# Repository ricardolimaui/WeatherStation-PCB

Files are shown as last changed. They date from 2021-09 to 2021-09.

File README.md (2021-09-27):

# Unparallel Weather Station PCB

The Unparallel Weather Station allows anyone to build their own low-cost weather station, using our custom open-source PCB. The software for the weather station is also open-source and can be used as is, or freely customized to meet your own needs and requirements. A model for printing a 3D case for your weather station is also provided.

This Weather Station PCB is a board to simplify the assembly of a weather station using low-cost hardware and a LoPy4 board. The LoPy4 board is equipped with several connectivity options (e.g. Sigfox, LoRa, Wi-Fi and Bluetooth). Currently, the weather station uses Sigfox and/or Wi-Fi to send the data to the cloud, however, the software can be extended to support other connectivity options. A Grafana dashboard is then used to display the historical weather data that is stored on the cloud.

The weather station uses an external sensor (AM2315) for reading temperature and relative humidity, a weather meter kit (SEN-15901) for wind speed, wind direction and precipitation. The weather station is powered from a Li-Ion battery that is charged with a photovoltaic panel which is also used to measure solar radiation. Due to the system’s low-power operation and solar energy harvesting features, it is energy autonomous and can be deployed in remote places.

## Measured parameters:  
*	Temperature (ºC)
*	Relative Humidity (%)
*	Rain (mm/h)
*	Wind Speed (km/h)
*	Wind Gust Speed (km/h)
*	Wind Direction (degrees)
*	Wind Gust Direction (degrees)
*	Solar Radiation (W/m2)
*	Battery Voltage (V)

## Parts list:  
*	Unparallel Weather Station PCB
*	Unparallel Weather Station 3D printed case (optional)
*	AM2315 - Encased I2C Temperature/Humidity Sensor
*	Weather Meter Kit - SEN-15901
*	Li-Ion battery (recommended 3.65V; 8Ah)
*	2.5W Solar Panel (116x160mm)
*	Sigfox antenna (868MHz)
*	LoPy 4.0

This work was done in the context of SmartAgriHubs Research Project, which has received funding from the European Union’s Horizon 2020 research and innovation programme under grant agreement No 818182

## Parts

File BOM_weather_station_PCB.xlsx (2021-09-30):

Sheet: pcb weatherstation
Qty per brd | Value | Device | Schematic Reference | Manufacturer Part Number (MPN) | MFR | Description
1 | - | LEDCHIP-LED0805 | LED1 | LG R971-KN-1 | Osram Opto Semiconductor | Standard LEDs - SMD 0805 Green, 570nm 26mcd, 20mA
1 | - | MCP73831/2 | U2 | MCP73831T-2ACI/OT | Microchip | Battery Management Charge
1 | - | PINHD-1X2 | JP2 | DS1023-1*2S21 | CONNFLY | Female; PIN: 2; straight; 2.54mm; THT; 1x2; 3A
1 | - | PINHD-1X6 | NCDW-06 | DS1023-1*6S21 | CONNFLY | Female; PIN: 6; straight; 2.54mm; THT; 1x6; 3A
2 | - | W237-102 | DC_IN SOLAR_POWER | DG300-5.0-2P12 | DEGSON ELECTRONICS | PCB terminal block; angled 90°; 5mm; ways: 2; on PCBs; 2.5mm2; 24A
2 | - | W237-4 | SENSOR1 | DG300-5.0-2P12 | DEGSON ELECTRONICS | PCB terminal block; angled 90°; 5mm; ways: 2; on PCBs; 2.5mm2; 24A
3 | 100k | R-EU_R0603 | R19 R20 R30 | RC0603FR-07100KL | YAGEO | Thick Film Resistors - SMD 0603 100 kOhms 100mW 0603 1%
2 | 100n | C-EUC0603 | C4 C9 | CC0603KRX7R8BB104 | YAGEO | MLCC - SMD/SMT 0603 25V 0.1uF X7R 0603 10%
2 | 10R | R-EU_R0603 | R11 R12 | CRCW060310R0FKEAC | Vishay | Thick Film Resistors - SMD 0603 1/10Watt 10ohms 1% Commercial Use
3 | 10k | R-EU_R0603 | R14 R15 R26 | CR0603-FX-1002ELF | Bourns | Thick Film Resistors - SMD 0603 10K 1% 1/10W
2 | 10n | C-EUC0603/C0805_PROTO | C1 C2 | 885012206089 | Wurth Elektronik | MLCC - SMD/SMT WCAP-CSGP 0.01uF 0603 10% 50V
7 | 1k | R-EU_R0603 | R1 R2 R3 R5 R6 R7 R18 | CR0603-FX-1001ELF | Bourns | Thick Film Resistors - SMD 0603 1K 1% 1/10W
1 | 2k74 | R-EU_R0603/R0805_PROTO | R29 | RC0603FR-132K74L | YAGEO | Thick Film Resistors - SMD 0603 2.74kOhms 1/10W 0603 1%
3 | 1u | C-EUC0603/C0805_PROTO | C5 C6 C7 | C0805C105K3RACTU | KEMET | MLCC - SMD/SMT 25V 1uF X7R 0805 10%
2 | 200k | R-EU_R0603/R0805_PROTO | R23 R25 | CRCW0603200KFKEAC | Vishay | Thick Film Resistors - SMD 0603 1/10Watt 200Kohms 1%
1 | 200m | R-EU_R0603/R0805_PROTO | R10 | RL1220S-R20-F | Susumu | Current Sense Resistors - SMD 0805 1/3W 0.20ohm 1%
1 | 220n | C-EUC0603 | C3 | CC0603KRX7R7BB224 | YAGEO | MLCC - SMD/SMT 16V 0.22uF X7R 0603 10%
4 | 47k | R-EU_R0603 | R13 R22 R27 R33 | RC0603FR-0747KL | YAGEO | Thick Film Resistors - SMD 47 kOhms 100mW 0603 1%
2 | 499k | R-EU_R0603/R0805_PROTO | R9 R24 | CR0603-FX-4993ELF | Bourns | Thick Film Resistors - SMD 499K ohm 1%
1 | 4k7 | R-EU_R0603/R0805_PROTO | R4 | RC0603FR-074K7L | YAGEO | Thick Film Resistors - SMD 4.7 kOhms 100mW 0603 1%
1 | 4u7 | C-EUC0603/C0805_PROTO | C8 | GRM21BZ7YA475KE15L | Murata | MLCC - SMD/SMT 35V 4.7uF X7R 0805 10%
3 | BSS138 | BSS138 | Q2 Q5 Q6 | BSS138-7-F | Diodes Incorporated | MOSFET 300mW 50V DSS SOT-23-3 N-channel
1 | CC/10k | R-EU_R0603 | R16 | Soldering Shunt
1 | CZRB5339B-HF | ZENER-DIODE-PROTO | D11 or D9 | CZRB5339B-HF Or 1N5339B-TP | Comchip Technology Or Micro Commercial Components (MCC) | Zener Diodes ZENER 5W 5.6V SMB DO-214AA-2 Or Zener Diodes 5.0W 5.6V 1uA 865mA 13.4A DO-15-2
1 | INA219BIDCNT | INA219BIDCNT | U1 | INA219BIDCNR | Texas Instruments | Current & Power Monitors & Regulators 0-Drift,Bi-dir Current/Pwr Monitor
2 | LOPY4 pinheader | LOPY4_SHIELD | U$2 | DS1023-1*14S21 | CONNFLY | Female; PIN: 14; straight; 2.54mm; THT; 1x14; 3A | e.g. https://www.adafruit.com/product/2940
1 | 220k | R-EU_R0603/R0805_PROTO | R8 | RC0603FR-0722KL | YAGEO | Thick Film Resistors - SMD 22 kOhms 100mW 0603 1%
2 | 0ZCK0075FF2E | PTC-0805 | F1 F2 | 0ZCK0075FF2E | Bel | Resettable Fuses - PPTC Hold current 750 mA 0805
2 | RFN2LAM4STFTR/SS14L | SCHOTTKY-DIODESMA_SOD-128_PROTO | D3 D10 | RFN2LAM4STFTR | ROHM Semiconductor | Diodes 400V VR 1.5A IO SOD-128; PMDTM
2 | RJ11 | RJ11-6 | J1_RAIN J2_WIND | 95501-2661 | Molex | Ethernet Connectors RA 6/6 RJ12 LOW PROFILE THT
1 | S2B-PH-SM4 | JST_2PIN-SMT-RA | CN1 | S2B-PH-SM4-TB | JST | Male; PH; 2mm; PIN: 2; SMT
2 | SI2333DDS_PROTO | SI2333DDS_PROTO | Q1 Q3 | SI2333DDS-T1-GE3 | Vishay | Transistor: P-MOSFET; unipolar; -12V; -5.2A; Idm: -20A; 1.1W; SOT23
1 | SN74AUP2G14DCKR | SN74AUP2G14-DCKR | U3 | SN74AUP2G14DCKR | Texas Instruments | Inverters Lo-Pwr Dual Schmitt- Trigger Inverter SC70-6
7 | SS12L | SCHOTTKY-DIODESUB_SMA_PROTO | D1 D2 D4 D6 D7 D8 D5 | SS14L | Taiwan Semiconductor | Schottky Rectifiers Sub SMA-2
1 | CC |  | JP1 | Soldering Shunt to vbat

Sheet: Part_list weatherstation
Qtd | Device | MPN | MFR | Description
1 | Battery (3.65V; 8Ah) | CL-18650-29E/1S3P | CELLEVIA BATTERIES | Li-Ion; Cell: SAMSUNG; 18650,MR18650; 3.65V; 8000mAh
1 | LoPy 4.0 | LoPy 4.0 | Pycom | WiFi Development Tools - 802.11 Sigfox, LoRa, 433MHZ BLE & WIFI Dev board
1 | Sigfox antenna (868MHz) | LoRa (868MHz/915MHz) & Sigfox Antenna Kit | Pycom | External antenna RF Cable Assemblies SMA(F)
1 | Solar Panel | 313070000 | Seeed Studio | Solar Panels 2.5W Solar Panel 116X160
1 | Temperature and Humidity sensor | AM 2315 (1293) | Adafruit | I2C Temp Humidity Sensor
1 | Weather Meters kit | SEN-15901 | SparkFun Electronics | Multiple Function Sensor Development Tools Weather Meter Kit (Rainfall, Weather, Wind Direction, Wind Speed)
1 | 3D box
1 | Weather Station PCB | Weather Station PCB

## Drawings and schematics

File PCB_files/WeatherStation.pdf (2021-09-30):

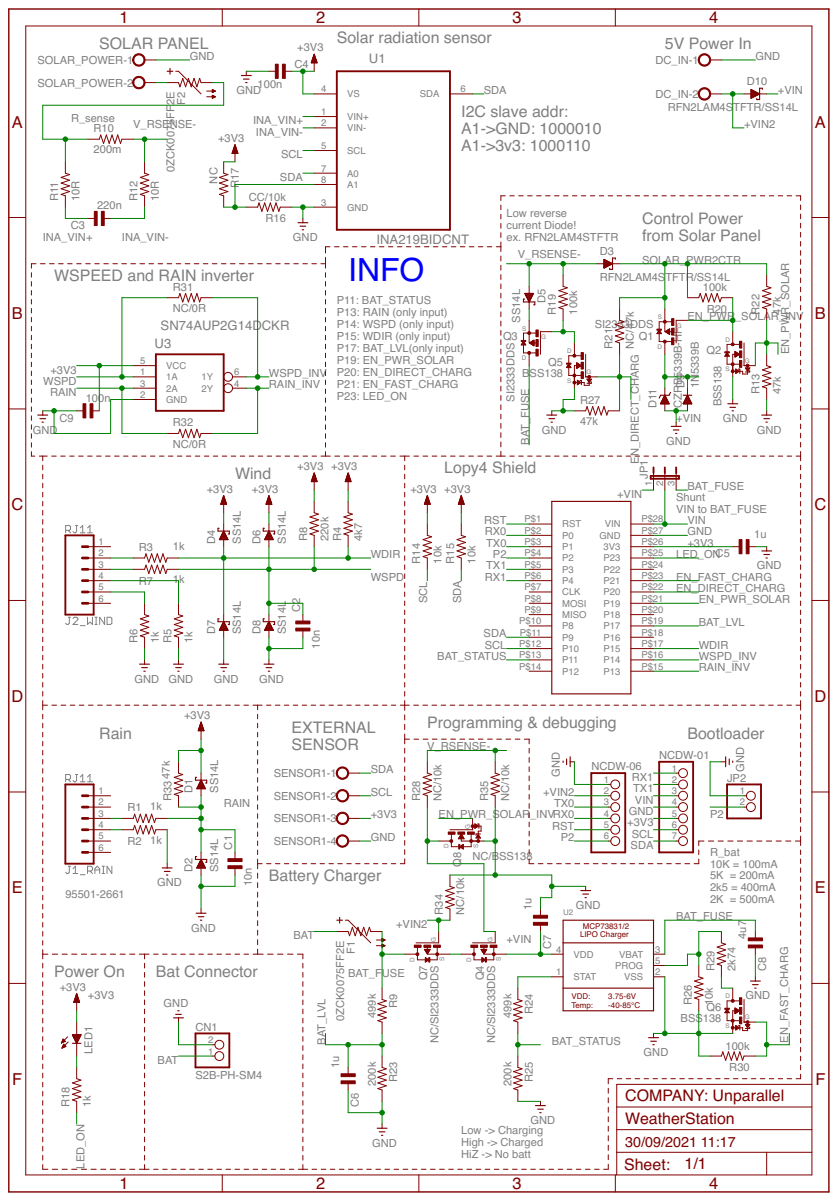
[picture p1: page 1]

Solar radiation sensor
NC/BSS138 NC/10k Low reverse

WSPEED and RAIN inverter

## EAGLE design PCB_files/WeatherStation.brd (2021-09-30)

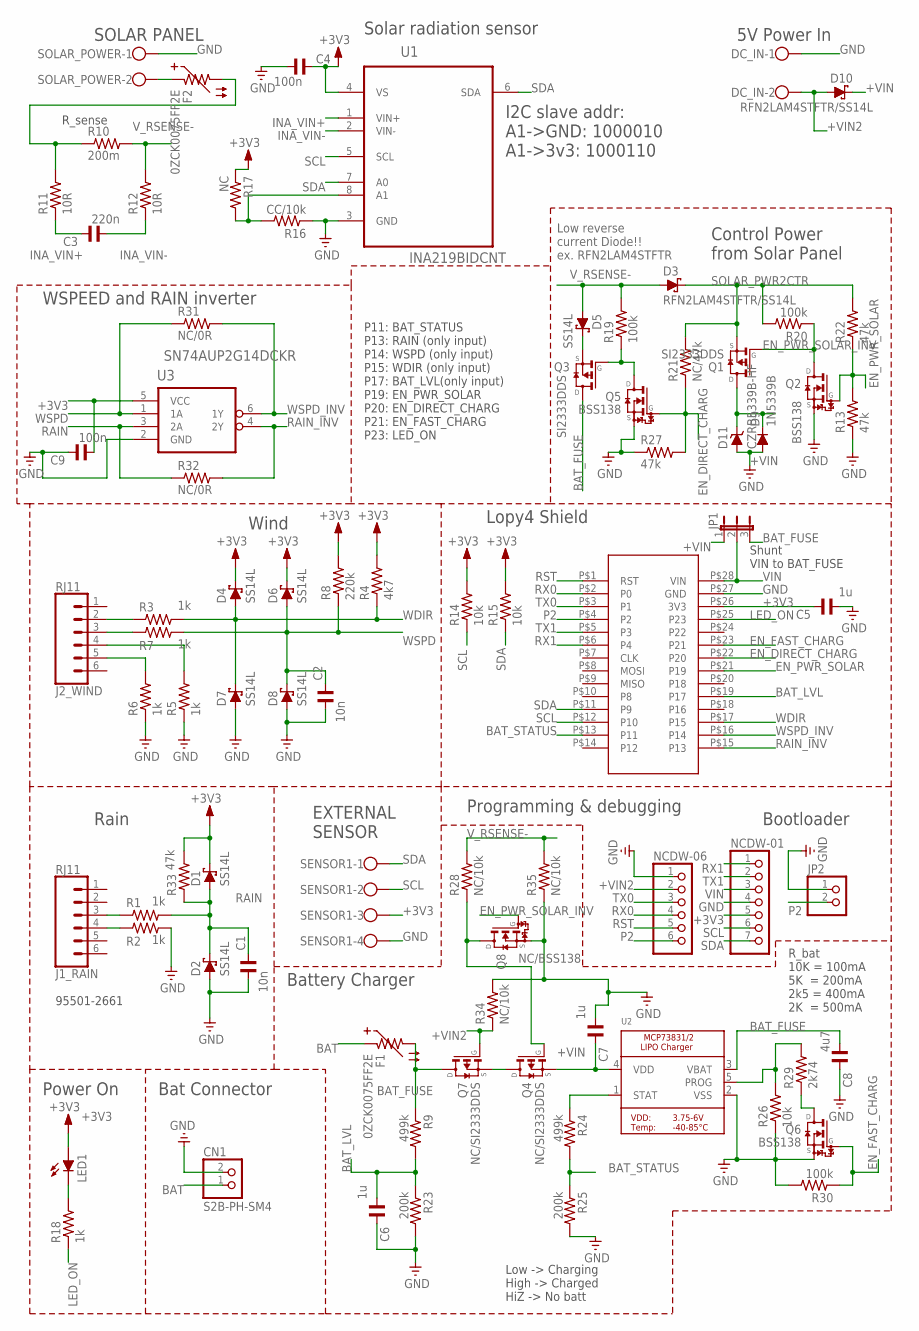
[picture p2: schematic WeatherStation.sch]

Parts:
C1, C2: 10n; C0603/C0805_PROTO_SLIM
C3: 220n; C0603
C4, C9: 100n; C0603
C5, C6, C7: 1u; C0603/C0805_PROTO_SLIM
C8: 4u7; C0603/C0805_PROTO_SLIM
CN1: S2B-PH-SM4; JST-PH-2-SMT-RA
D1, D2, D4, D5, D6, D7, D8: SS14L; SUB_SMA_PROTO
D3, D10: RFN2LAM4STFTR/SS14L; SMA_SOD-128_PROTO
D9: 1N5339B; DO15-12
D11: CZRB5339B-HF; SMB_PROTO
DC_IN: W237-102
F1: 0ZCK0075FF2E; R0603/R0805_PROTO_SLIM
F2: 0ZCK0075FF2E; R0805
J1_RAIN, J2_WIND: RJ11; RJ11-6
JP1: JP2E-0805; R0805/2
JP2: PINHD-1X2; 1X02
LED1: LEDCHIP-LED0805; CHIP-LED0805
NCDW-01: PINHD-1X7; 1X07
NCDW-06: PINHD-1X6; 1X06
Q1, Q3: SI2333DDS; SOT23_PROTO_SLIM
Q2, Q5, Q6: BSS138; SOT23_PROTO_SLIM
Q4, Q7: NC/SI2333DDS; SOT23_PROTO_SLIM
Q8: NC/BSS138; SOT23_PROTO_SLIM
R1, R2, R3, R5, R6, R7, R18: 1k; R0603
R4: 4k7; R0603/R0805_PROTO_SLIM
R8: 220k; R0603/R0805_PROTO_SLIM
R9, R24: 499k; R0603/R0805_PROTO_SLIM
R10: 200m; R0603/R0805_PROTO_SLIM
R11, R12: 10R; R0603
R13, R22, R27, R33: 47k; R0603
R14, R15: 10k; R0603
R16: CC/10k; R0603
R17: NC; R0603
R19, R20: 100k; R0603
R21: NC/47k; R0603
R23, R25: 200k; R0603/R0805_PROTO_SLIM
R26: 10k; R0603/R0805_PROTO_SLIM
R28, R34, R35: NC/10k; R0603
R29: 2k74; R0603/R0805_PROTO_SLIM
R30: 100k; R0603/R0805_PROTO_SLIM
R31, R32: NC/0R; R0603/R0805_PROTO_SLIM
SENSOR1: W237-4
SOLAR_POWER: W237-102
U1: INA219BIDCNT; SOT65P280X145-8N
U2: MCP73831/2; SOT23-5
U3: SN74AUP2G14DCKR; SOT65P210X110-6N_EDIT
U$2: LOPY4_SHIELD

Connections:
+3V3: C4.1, C5.1, C9.2, D1.C, D4.C, D6.C, LED1.A, NCDW-01.5, R4.2, R8.2, R14.2, R15.2, R17.1, R33.2, SENSOR1.3, U1.4 (VS), U3.5 (VCC), U$2.P$26 (3V3)
+VIN: C7.1, D9.C, D10.C, D11.C, JP1.1, Q1.3 (D), Q4.2 (S), U2.4 (VDD)
+VIN2: D10.A, DC_IN.2, NCDW-06.2, Q7.1 (G), R34.1
BAT: CN1.1 (2), F1.1
BAT_FUSE: C8.2, F1.2, JP1.3, Q3.3 (D), Q7.3 (D), R9.1, U2.3 (VBAT)
BAT_LVL: C6.2, R9.2, R23.1, U$2.P$19 (P17)
BAT_STATUS: R24.2, R25.1, U$2.P$13 (P11)
EN_DIRECT_CHARG: Q5.1 (G), R21.1, R27.2, U$2.P$22 (P20)
EN_FAST_CHARG: Q6.1 (G), R30.1, U$2.P$23 (P21)
EN_PWR_SOLAR: Q2.1 (G), R13.2, R22.1, U$2.P$21 (P19)
EN_PWR_SOLAR_INV: Q1.1 (G), Q2.3 (D), Q8.1 (G), R20.1
GND: C1.2, C2.2, C4.2, C5.2, C6.1, C7.2, C8.1, C9.1, CN1.2 (1), D2.A, D7.A, D8.A, D9.A, D11.A, DC_IN.1, JP2.1, NCDW-01.4, NCDW-06.1, Q2.2 (S), Q5.2 (S), Q6.2 (S), Q8.2 (S), R2.2, R5.1, R6.1, R13.1, R16.1, R23.2, R25.2, R26.1, R27.1, R30.2, R34.2, R35.1, SENSOR1.4, SOLAR_POWER.1, U1.3 (GND), U2.2 (VSS), U3.2 (GND), U$2.P$27 (GND)
INA_VIN+: C3.1, R11.1, U1.1 (VIN+)
INA_VIN-: C3.2, R12.1, U1.2 (VIN-)
LED_ON: R18.1, U$2.P$25 (P23)
unnamed: D5.C, Q3.2 (S)
unnamed: F2.1, SOLAR_POWER.2
unnamed: J1_RAIN.4, R2.1
unnamed: J1_RAIN.3, R1.1
unnamed: J2_WIND.2, R3.1
unnamed: J2_WIND.3, R7.1
unnamed: J2_WIND.4, R5.2
unnamed: J2_WIND.5, R6.2
unnamed: Q4.1 (G), Q8.3 (D), R28.1
unnamed: R26.2, R29.2, U2.5 (PROG)
unnamed: R16.2, R17.2, U1.8 (A1)
unnamed: LED1.C, R18.2
unnamed: Q6.3 (D), R29.1
unnamed: Q3.1 (G), Q5.3 (D), R19.1
unnamed: R24.1, U2.1 (STAT)
unnamed: Q4.3 (D), Q7.2 (S)
P2: JP2.2, NCDW-06.6, U$2.P$4 (P2)
RAIN: C1.1, D1.A, D2.C, R1.2, R32.1, R33.1, U3.3 (2A)
RAIN_INV: R32.2, U3.4 (2Y), U$2.P$15 (P13)
RST: NCDW-06.5, U$2.P$1 (RST)
RX0: NCDW-06.4, U$2.P$2 (P0)
RX1: NCDW-01.1, U$2.P$6 (P4)
SCL: NCDW-01.6, R14.1, SENSOR1.2, U1.5 (SCL), U$2.P$12 (P10)
SDA: NCDW-01.7, R15.1, SENSOR1.1, U1.6 (SDA), U1.7 (A0), U$2.P$11 (P9)
SOLAR_PWR2CTR: D3.C, Q1.2 (S), R20.2, R21.2, R22.2
TX0: NCDW-06.3, U$2.P$3 (P1)
TX1: NCDW-01.2, U$2.P$5 (P3)
VBUS_SOLAR: F2.2, R10.1, R11.2
VIN: JP1.2, NCDW-01.3, U$2.P$28 (VIN)
V_RSENSE-: D3.A, D5.A, R10.2, R12.2, R19.2, R28.2, R35.2
WDIR: D4.A, D7.C, R3.2, R4.1, U$2.P$17 (P15)
WSPD: C2.1, D6.A, D8.C, R7.2, R8.1, R31.1, U3.1 (1A)
WSPD_INV: R31.2, U3.6 (1Y), U$2.P$16 (P14)

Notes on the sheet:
Lopy4 Shield
EXTERNAL SENSOR
SOLAR PANEL
Rain
Wind
Solar radiation sensor
I2C slave addr: A1->GND: 1000010 A1->3v3: 1000110
Power On
5V Power In
P11: BAT_STATUS P13: RAIN (only input) P14: WSPD (only input) P15: WDIR (only input) P17: BAT_LVL(only input) P19: EN_PWR_SOLAR P20: EN_DIRECT_CHARG P21: EN_FAST_CHARG P23: LED_ON
Programming & debugging
Control Power from Solar Panel
R_bat 10K = 100mA 5K = 200mA 2k5 = 400mA 2K = 500mA
Low -> Charging High -> Charged HiZ -> No batt
Battery Charger
Bootloader
R_sense
95501-2661
Low reverse current Diode!! ex. RFN2LAM4STFTR
WSPEED and RAIN inverter
Bat Connector
Shunt VIN to BAT_FUSE

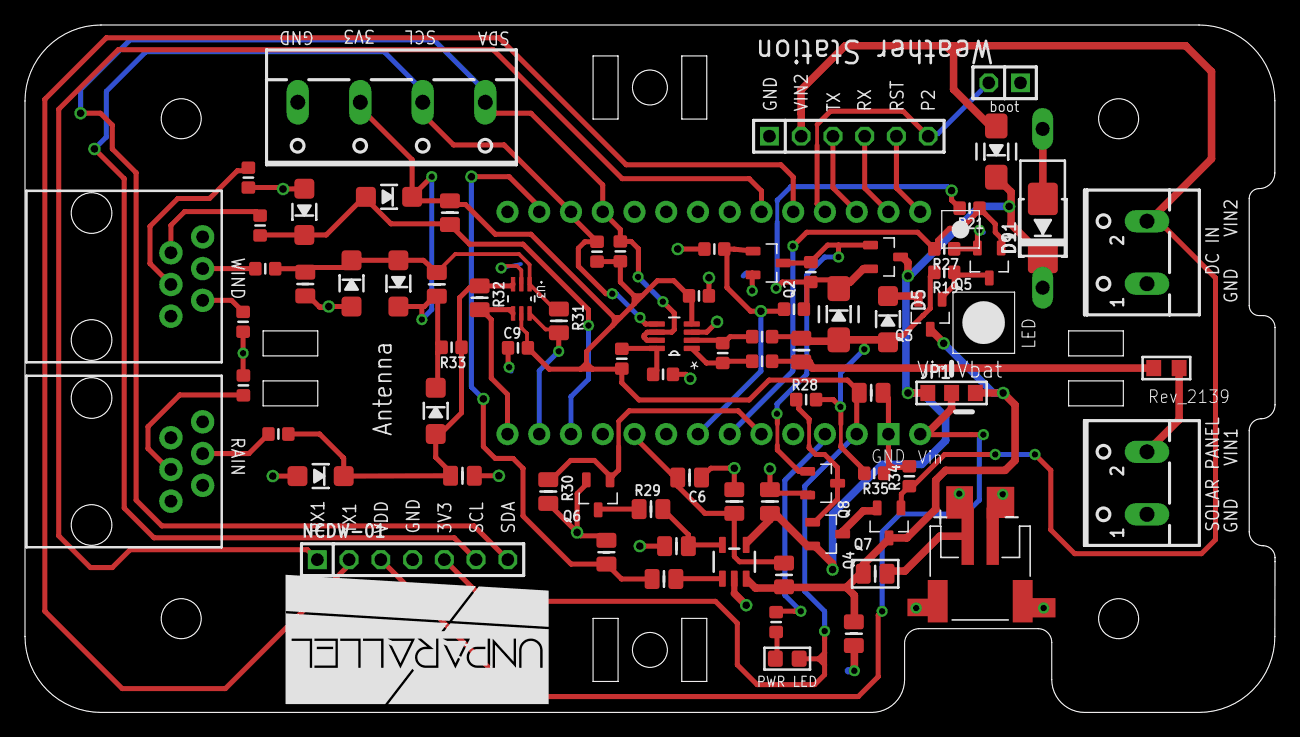
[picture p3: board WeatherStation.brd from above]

Board: 2 copper layers, 100.0 x 55.0 mm, 83 parts (0 on the bottom side), 48 nets.

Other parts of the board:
STAND2, STAND3: MOUNTHOLE_110MIL
U$1: UNPARALLEL_LOGO_NEW_0_INVERT_BIG

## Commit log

2021-09-27 Create PCB_files
2021-09-27 Eagles files WeatherStation_0v9
    [WeatherStation_pcb.brd, WeatherStation_pcb.sch]
2021-09-27 Gerber files WeatherStation_0v9
    [gerber_d2131.GBL, gerber_d2131.GBO, gerber_d2131.GBS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]
2021-09-27 BOM and parts list
    [BOM_weather_station_PCB.xlsx]

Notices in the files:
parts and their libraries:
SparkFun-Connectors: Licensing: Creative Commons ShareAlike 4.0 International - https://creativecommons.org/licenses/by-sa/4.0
